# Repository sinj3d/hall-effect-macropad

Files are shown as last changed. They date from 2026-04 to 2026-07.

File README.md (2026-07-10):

# Custom Hall-Effect Macropad





## Overview
A custom-engineered macropad utilizing entirely 3D-printed Hall-effect switches. This project demonstrates end-to-end hardware design, from schematic capture and PCB layout to physical assembly and mechanism tuning. [cite_start]The hardware serves as a development platform for writing custom peripheral firmware in C++ and Rust[cite: 4].

<div align="center">
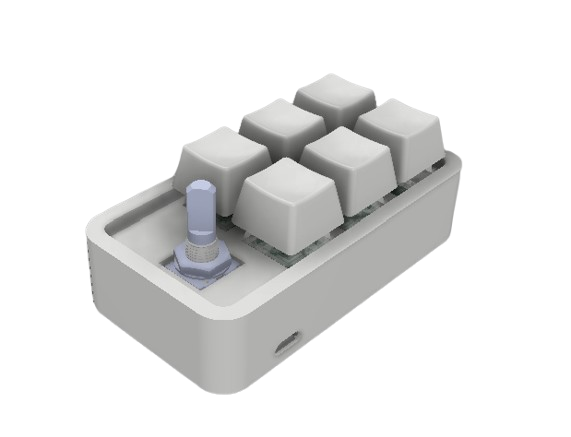
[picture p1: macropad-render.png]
Physical PCB Assembly
  
</div>

## Current Status & Next Steps
**Hardware V1 is fully assembled and mechanically functional.** The custom PCB has been fabricated, populated, and soldered. The 3D-printed magnetic switches are currently undergoing physical fine-tuning to optimize the keystroke smoothness and actuation tolerances. 

**Immediate Next Steps:**
* [cite_start]**Firmware Architecture:** Drafting the low-level firmware in C++/Rust [cite: 4] to handle analog matrix scanning and switch debouncing.
* **Actuation Calibration:** Implementing dynamic actuation point calibration based on the analog Hall-effect sensor outputs.
* **Enclosure Design:** Finalizing the CAD for the external housing.

## Hardware Specifications
* **PCB Design:** Custom 2-layer board designed in KiCad.
* **Switches:** Custom 3D-printed housings utilizing Hall-effect sensors and permanent magnets for frictionless, adjustable actuation.
* **Manufacturing:** Routing, ground pours, and component placement optimized for hand-soldering and mechanical stability.

## Repository Structure

This repository contains the complete hardware definition and firmware files.

* `/Hardware`
    * `/Gerbers` - Ready-to-manufacture fabrication files (Copper, Mask, Silkscreen, Edge Cuts, Drill files).
    * `Macropad Schematic.pdf` - High-resolution electrical schematic for quick review.
    * `/KiCad_Project` - Raw `.kicad_pro`, `.kicad_sch`, and `.kicad_pcb` source files.
* `/CAD`
    * .STL files for the 3D-printed switch mechanisms.
* `/Firmware`
    * `main.cpp` - Firmware source (PlatformIO / Arduino framework)
    * `config.h` - Pin map, keymap, and tuning constants
    * `README.md` - Build, flash, tuning, and troubleshooting guide

## Firmware Quick Start

```bash
pip install platformio
pio run -t upload        # from the repo root, Pro Micro plugged in
pio device monitor       # 115200 baud; type 'h' for tuning commands
```

See [Firmware/README.md](Firmware/README.md) for the pin map, key remapping, sensor tuning, and troubleshooting.

## Visuals & Renders

| PCB Soldered| Schematic Design | Switch Render | 
| :---: | :---: | :---: |
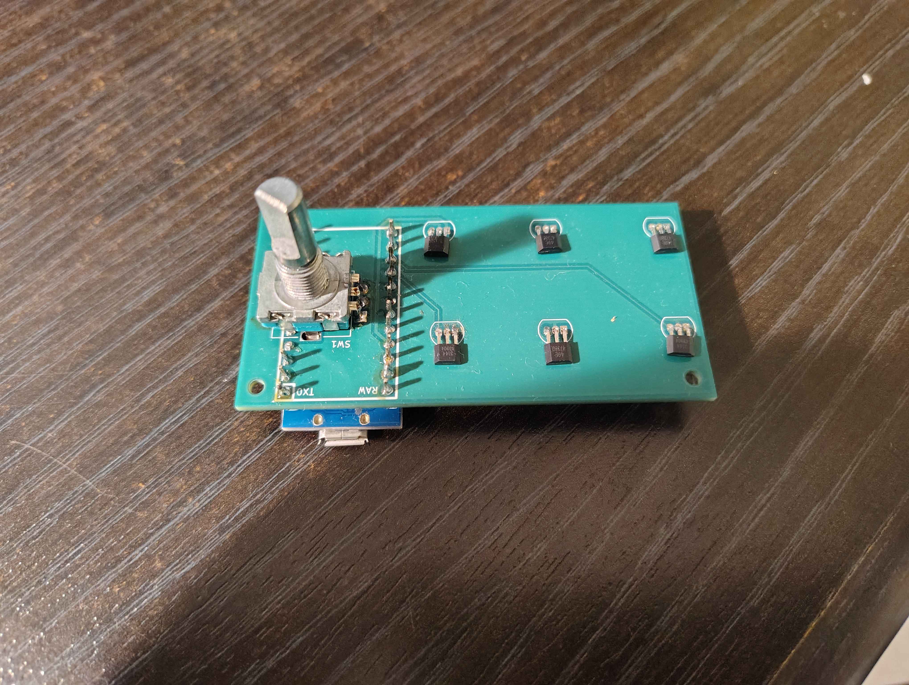
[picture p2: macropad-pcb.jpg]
PCB
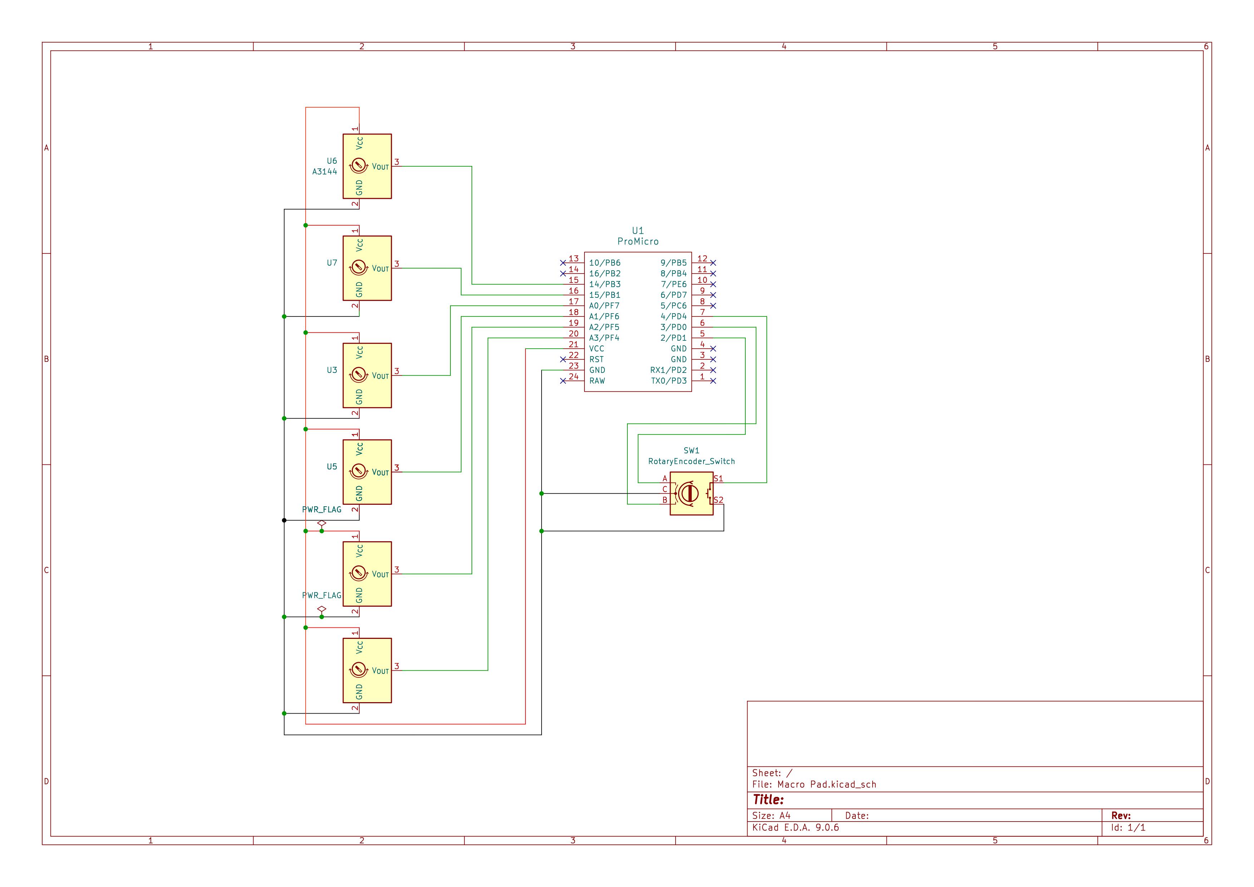
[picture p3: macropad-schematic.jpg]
Schematic
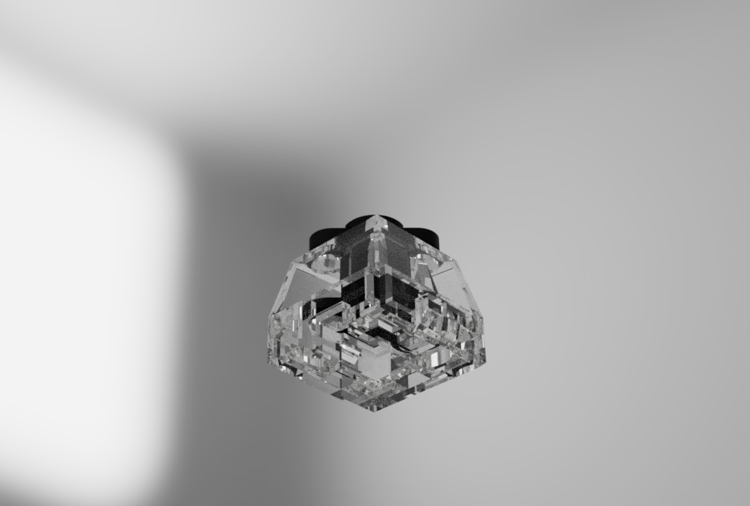
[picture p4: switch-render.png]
Switch
|  |  |

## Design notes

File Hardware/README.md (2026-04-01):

# Custom Hall-Effect Macropad





## Overview
A custom-engineered macropad utilizing entirely 3D-printed Hall-effect switches. This project demonstrates end-to-end hardware design, from schematic capture and PCB layout to physical assembly and mechanism tuning. [cite_start]The hardware serves as a development platform for writing custom peripheral firmware in C++ and Rust[cite: 4].

<div align="center">
  Physical PCB Assembly
</div>

## Current Status & Next Steps
**Hardware V1 is fully assembled and mechanically functional.** The custom PCB has been fabricated, populated, and soldered. The 3D-printed magnetic switches are currently undergoing physical fine-tuning to optimize the keystroke smoothness and actuation tolerances. 

**Immediate Next Steps:**
* [cite_start]**Firmware Architecture:** Drafting the low-level firmware in C++/Rust [cite: 4] to handle analog matrix scanning and switch debouncing.
* **Actuation Calibration:** Implementing dynamic actuation point calibration based on the analog Hall-effect sensor outputs.
* **Enclosure Design:** Finalizing the CAD for the external housing.

## Hardware Specifications
* **PCB Design:** Custom 2-layer board designed in KiCad.
* **Switches:** Custom 3D-printed housings utilizing Hall-effect sensors and permanent magnets for frictionless, adjustable actuation.
* **Manufacturing:** Routing, ground pours, and component placement optimized for hand-soldering and mechanical stability.

## Repository Structure

This repository contains the complete hardware definition files needed to replicate the board.

* `/Hardware`
    * `/Gerbers` - Ready-to-manufacture fabrication files (Copper, Mask, Silkscreen, Edge Cuts, Drill files).
    * `macropad_schematic.pdf` - High-resolution electrical schematic for quick review.
    * `/KiCad_Project` - Raw `.kicad_pro`, `.kicad_sch`, and `.kicad_pcb` source files.
* `/CAD`
    * .STL files for the 3D-printed switch mechanisms.

## Visuals & Renders

| Schematic Design | 3D PCB Render |
| :---: | :---: |
| Schematic | 3D Render |

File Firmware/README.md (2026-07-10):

# Macropad Firmware

Firmware for the 6-key + rotary-encoder Hall-effect macropad, running on a SparkFun Pro Micro (ATmega32U4). Built with PlatformIO on the Arduino framework, using [HID-Project](https://github.com/NicoHood/HID) for NKRO keyboard and media-key (consumer control) output.

## Hardware

| Signal | Pro Micro pin | MCU port | Notes |
|---|---|---|---|
| SS49E sensor 0–3 (WASD) | A3, A2, A1, A0 | PF4–PF7 | Linear analog output, idles near VCC/2 |
| A3144 switch 0 | 15 | PB1 | Open collector, LOW when magnet present |
| A3144 switch 1 | 14 | PB3 | Open collector, LOW when magnet present |
| Encoder A | 2 | PD1 / INT1 | Interrupt-driven quadrature |
| Encoder B | 3 | PD0 / INT0 | Interrupt-driven quadrature |
| Encoder push switch | 4 | PD4 | Active LOW |

The SS49Es must be on A0–A3: PB1/PB3 have no ADC, so those two positions can only host the digital A3144s.

### How analog sensing works

The SS49E idles near VCC/2 and its output swings **up or down** as the magnet approaches, depending on which pole faces the sensor. The firmware captures a per-key baseline at power-up and treats a key as pressed when the reading deviates from that baseline by `ACTUATION_DELTA` counts (released when it falls back below `RELEASE_DELTA`). This works with either magnet orientation and needs no per-key polarity configuration.

Consequence: **don't hold keys down while plugging the board in.** If you did, send `z` over serial to re-capture baselines. Slow drift (temperature, magnet creep) is compensated automatically while keys are idle.

## Build & flash

```bash
pip install platformio        # once
pio run                       # compile (from the repo root)
pio run -t upload             # compile + flash, port auto-detected
pio device monitor            # serial console, 115200 baud
```

If `pio` isn't recognized after installing (pip's Scripts directory not on PATH), use `python -m platformio` in place of `pio` — e.g. `python -m platformio run -t upload`.

If the upload times out, double-tap the reset button on the Pro Micro (this enters the Caterina bootloader for ~8 seconds) and run the upload command again.

## Serial commands (115200 baud)

| Key | Action |
|---|---|
| `v` | Print one status line: filtered value, baseline, and delta/actuation per analog key, digital key states, raw encoder pin levels |
| `p` | Toggle 10 Hz streaming of that status line (use while tuning) |
| `z` | Re-capture analog baselines (release all keys first) |
| `c` | Guided per-key actuation calibration (results saved to EEPROM) |
| `d` | Clear saved calibration, back to the `config.h` defaults |
| `h` | Help |

## Calibrating actuation points (per key)

Each analog key has its own actuation and release point, calibrated in place:

1. Run `pio device monitor` and send `c`.
2. Keep all keys released while it re-zeros, then press and **hold** each WASD key fully, one at a time. Peak travel per key is echoed once a second.
3. After 15 s (or send any character to finish early), each key's actuation point is set to 65% of its measured travel and its release point to 35%, the results are printed, and everything is saved to EEPROM — calibration survives power cycles and re-flashing.

Keys that moved less than `CAL_MIN_TRAVEL` (30 counts) during the window keep their previous thresholds, so you can re-calibrate a single key without touching the others. The 65/35 split is set by `CAL_ACTUATION_PCT` / `CAL_RELEASE_PCT` in `config.h`; the gap between them is the hysteresis that debounces the analog keys — keep it wide to avoid chatter.

Until calibration is run (or after `d` clears it), all keys use the `ACTUATION_DELTA` / `RELEASE_DELTA` defaults from `config.h` (60/35 counts); a close-range neodymium magnet typically swings 150–300 counts at full press.

## Verifying the physical layout

The schematic doesn't say which physical key sits on which pin, so verify once:

- **Key order**: stream with `p`, press each key, and note which channel (`A0`–`A3`, `D0`/`D1`) responds. Reorder `ANALOG_KEY_MAP` / `DIGITAL_KEY_MAP` in `config.h` to match.
- **Encoder pins**: the firmware assumes A=D2, B=D3, switch=D4. Watching the `enc A= B= SW=` fields while rotating slowly and pressing shows which pins actually toggle; adjust `PIN_ENC_*` in `config.h` if they're crossed.
- **Encoder direction**: if volume goes the wrong way, set `ENCODER_REVERSED` to `1`.

## Changing the keymap

Edit `config.h`:

```cpp
static const KeyboardKeycode ANALOG_KEY_MAP[NUM_ANALOG_KEYS] = {KEY_W, KEY_A, KEY_S, KEY_D};
static const KeyboardKeycode DIGITAL_KEY_MAP[NUM_DIGITAL_KEYS] = {KEY_LEFT_SHIFT, KEY_SPACE};

static const ConsumerKeycode ENC_CW_ACTION = MEDIA_VOLUME_UP;
static const ConsumerKeycode ENC_CCW_ACTION = MEDIA_VOLUME_DOWN;
static const ConsumerKeycode ENC_PRESS_ACTION = MEDIA_PLAY_PAUSE;
```

Key names are HID-Project's `KeyboardKeycode` (`KEY_A`–`KEY_Z`, `KEY_F1`–`KEY_F24`, `KEY_LEFT_CTRL`, `KEY_ESC`, ...) and `ConsumerKeycode` (`MEDIA_VOLUME_UP`, `MEDIA_VOL_MUTE`, `MEDIA_NEXT`, `CONSUMER_BROWSER_HOME`, ...). Full lists are in HID-Project's `ImprovedKeylayouts.h` and `ConsumerAPI.h`.

## Troubleshooting

- **An A3144 key never triggers**: the A3144 is unipolar — it only responds to the magnet's **south pole**. Flip the magnet in that switch stem.
- **An analog key is stuck down or dead**: its baseline is probably wrong (key was held at power-up, or the magnet moved). Send `z` with all keys released. If deltas barely move on press, the magnet may be too far from the sensor at the bottom of travel.
- **Encoder skips or double-steps**: try `ENC_STEPS_PER_DETENT = 2` (some encoders are half-step per detent).
- **Upload fails**: double-tap reset, then upload within ~8 seconds. Check `pio device list` shows the board.
- **Two keys are dead**: they're likely the PB1/PB3 positions with SS49Es installed there by mistake — those pins can't do analog. Swap the sensors so the A3144s sit on PB1/PB3.

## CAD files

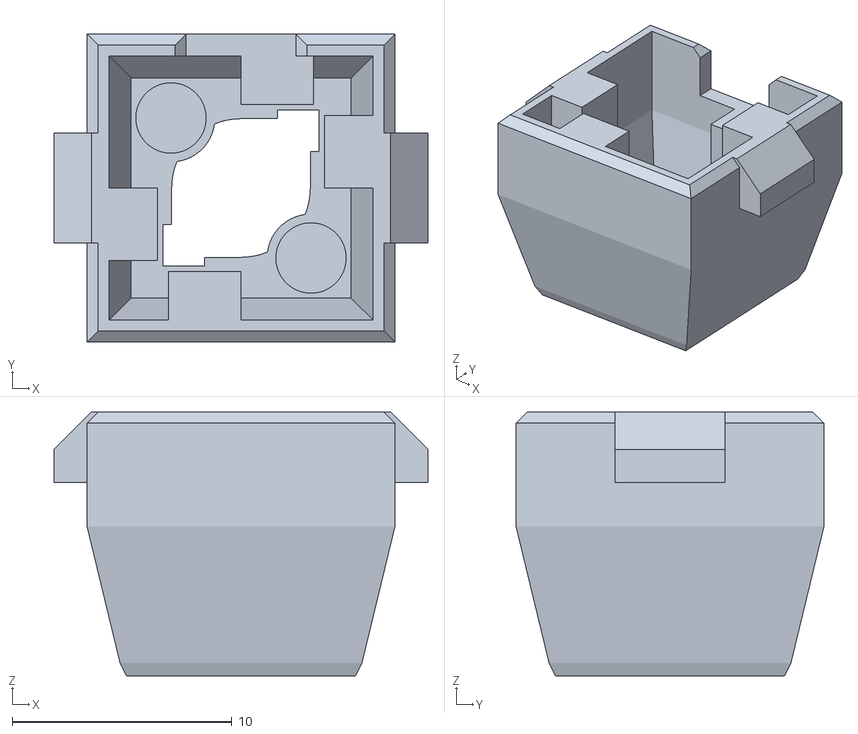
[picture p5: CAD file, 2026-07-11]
CAD/Key Base.stl
17.0 x 14.0 x 12.0

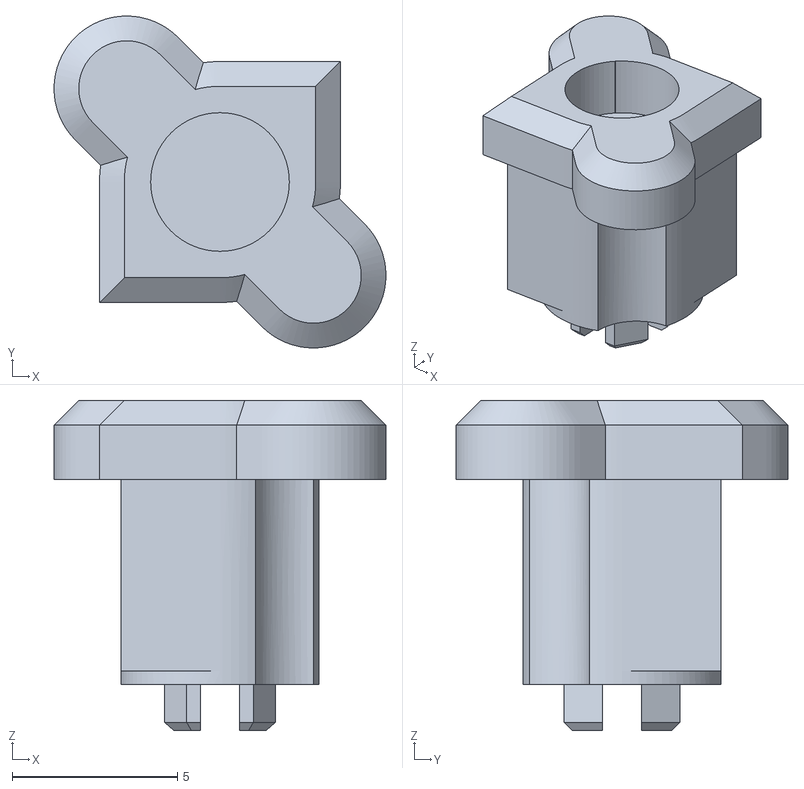
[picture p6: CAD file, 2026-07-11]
CAD/key stem bottom.stl
10.1 x 10.1 x 10.0

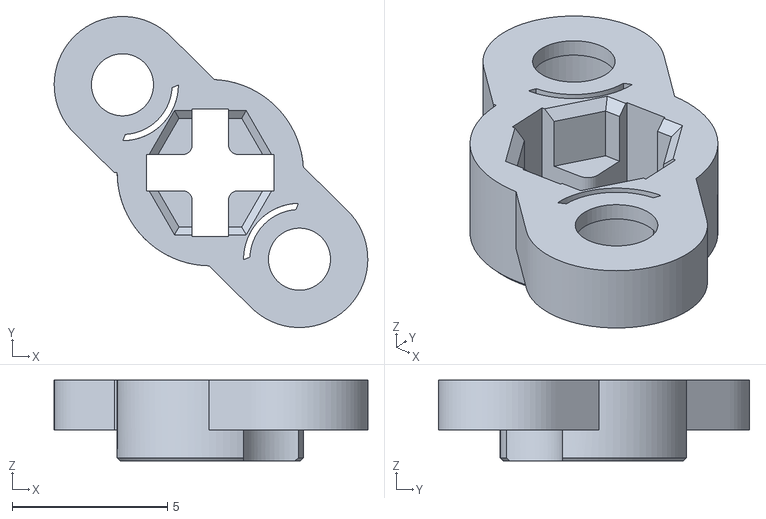
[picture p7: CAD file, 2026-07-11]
CAD/Key stem top.stl
10.1 x 10.0 x 2.60

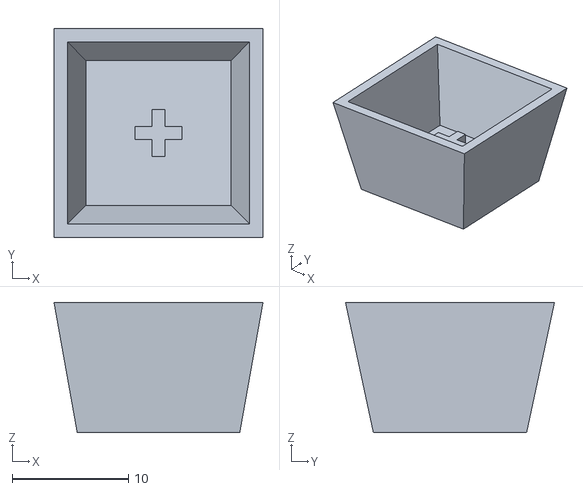
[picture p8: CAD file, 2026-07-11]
CAD/Keycap.stl
18.0 x 18.0 x 11.2

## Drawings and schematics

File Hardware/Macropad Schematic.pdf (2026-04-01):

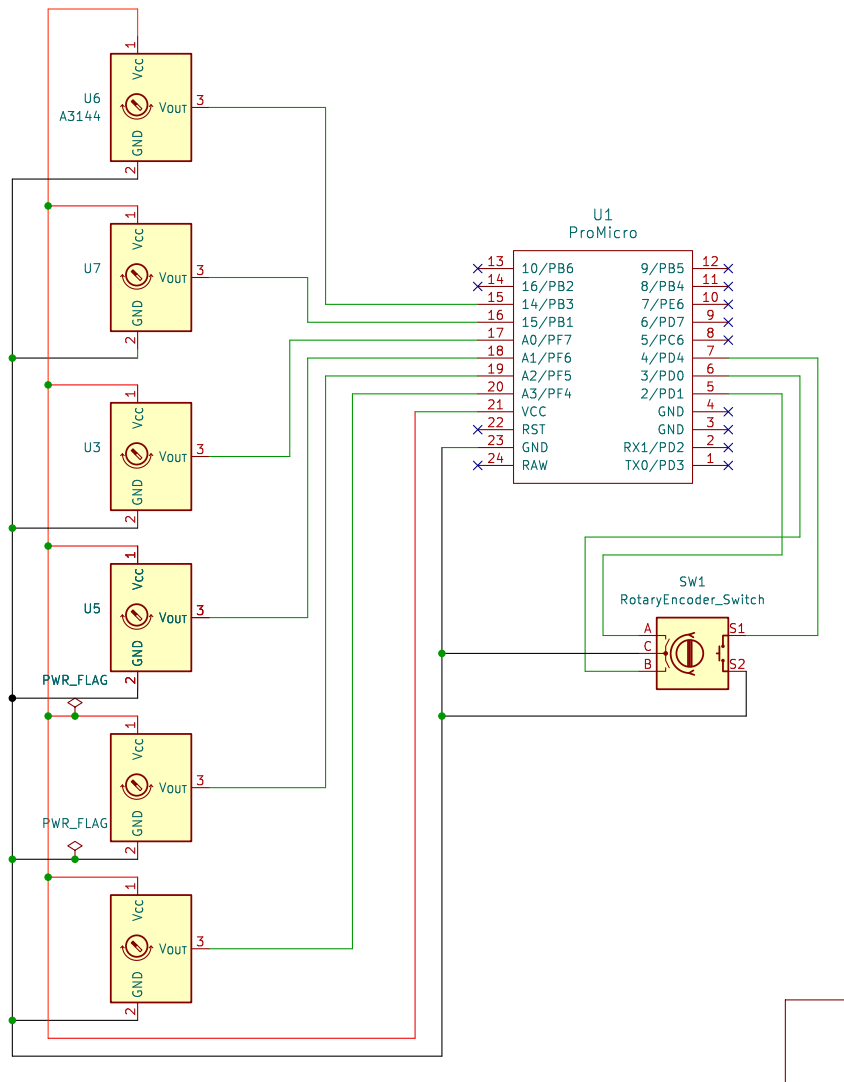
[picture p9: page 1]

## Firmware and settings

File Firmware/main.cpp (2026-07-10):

/*
 * Hall-effect macropad firmware
 * Board: SparkFun Pro Micro (ATmega32U4, 5V/16MHz)
 *
 * Hardware, per Hardware/Macropad Schematic.pdf:
 *   - 4x SS49E linear Hall sensors (analog) on A3/A2/A1/A0 — WASD cluster
 *   - 2x A3144 Hall switches (open collector, active LOW) on D15/D14
 *   - Rotary encoder: A/B on D2/D3 (external interrupts), push switch on D4
 *
 * SS49E keys: the sensor idles near VCC/2 and swings up or down as the magnet
 * approaches, depending on which pole faces it. Each key is compared against a
 * baseline captured at power-up; it counts as pressed once the reading deviates
 * from that baseline by ACTUATION_DELTA and releases below RELEASE_DELTA, so
 * either magnet orientation works. Don't hold keys while plugging the board in
 * (send 'z' over serial to re-zero if you did).
 *
 * Actuation points are per key: serial command 'c' measures each key's full
 * travel and stores actuation/release thresholds in EEPROM ('d' clears them).
 */

#include <Arduino.h>
#include <EEPROM.h>
#include "config.h"

// ---------- SS49E (analog) keys ----------

struct AnalogKey {
  uint16_t filtered;
  uint16_t baseline;
  bool pressed;
};

static AnalogKey analogKeys[NUM_ANALOG_KEYS];

static uint16_t readAveraged(uint8_t pin, uint8_t samples) {
  uint16_t sum = 0;
  for (uint8_t i = 0; i < samples; i++) sum += analogRead(pin);
  return sum / samples;
}

static void captureBaselines() {
  for (uint8_t i = 0; i < NUM_ANALOG_KEYS; i++) {
    analogKeys[i].baseline = readAveraged(ANALOG_KEY_PINS[i], 32);
    analogKeys[i].filtered = analogKeys[i].baseline;
  }
}

static uint16_t deltaFromBaseline(const AnalogKey &k) {
  return k.filtered > k.baseline ? k.filtered - k.baseline : k.baseline - k.filtered;
}

// ---------- Per-key actuation thresholds (EEPROM-backed) ----------

struct Calibration {
  uint8_t magic;
  uint16_t actuation[NUM_ANALOG_KEYS];
  uint16_t release[NUM_ANALOG_KEYS];
};

static const uint8_t CAL_MAGIC = 0xC4;
static Calibration cal;

static void loadDefaultCal() {
  for (uint8_t i = 0; i < NUM_ANALOG_KEYS; i++) {
    cal.actuation[i] = ACTUATION_DELTA;
    cal.release[i] = RELEASE_DELTA;
  }
}

static void loadCalibration() {
  Calibration stored;
  EEPROM.get(0, stored);
  if (stored.magic == CAL_MAGIC) cal = stored;
  else loadDefaultCal();
}

static void saveCalibration() {
  cal.magic = CAL_MAGIC;
  EEPROM.put(0, cal);  // update semantics: only changed bytes get written
}

static void scanAnalogKeys() {
  for (uint8_t i = 0; i < NUM_ANALOG_KEYS; i++) {
    AnalogKey &k = analogKeys[i];
    uint16_t raw = readAveraged(ANALOG_KEY_PINS[i], ADC_SAMPLES);
    k.filtered = (k.filtered * 3 + raw + 2) / 4;

    uint16_t delta = deltaFromBaseline(k);
    if (!k.pressed && delta >= cal.actuation[i]) {
      k.pressed = true;
      NKROKeyboard.press(ANALOG_KEY_MAP[i]);
    } else if (k.pressed && delta <= cal.release[i]) {
      k.pressed = false;
      NKROKeyboard.release(ANALOG_KEY_MAP[i]);
    }
  }
}

// Nudge idle baselines one count toward the current reading so slow drift
// (temperature, magnet creep) doesn't eat into the actuation margin.
static void trackBaselineDrift() {
  static uint32_t lastMs = 0;
  uint32_t now = millis();
  if (now - lastMs < BASELINE_TRACK_MS) return;
  lastMs = now;
  for (uint8_t i = 0; i < NUM_ANALOG_KEYS; i++) {
    AnalogKey &k = analogKeys[i];
    if (k.pressed || deltaFromBaseline(k) > cal.release[i]) continue;
    if (k.filtered > k.baseline) k.baseline++;
    else if (k.filtered < k.baseline) k.baseline--;
  }
}

// ---------- A3144 (digital) keys + encoder button ----------

struct DebouncedInput {
  bool state;
  bool lastReading;
  uint32_t lastEdgeMs;
};

static DebouncedInput digitalKeys[NUM_DIGITAL_KEYS];
static DebouncedInput encButton;

// Returns true when the debounced state just changed.
static bool debounce(DebouncedInput &d, bool reading, uint32_t now) {
  if (reading != d.lastReading) {
    d.lastReading = reading;
    d.lastEdgeMs = now;
  }
  if (reading != d.state && now - d.lastEdgeMs >= DEBOUNCE_MS) {
    d.state = reading;
    return true;
  }
  return false;
}

static void scanDigitalKeys() {
  uint32_t now = millis();
  for (uint8_t i = 0; i < NUM_DIGITAL_KEYS; i++) {
    bool active = digitalRead(DIGITAL_KEY_PINS[i]) == LOW;  // sinks LOW near magnet
    if (debounce(digitalKeys[i], active, now)) {
      if (digitalKeys[i].state) NKROKeyboard.press(DIGITAL_KEY_MAP[i]);
      else NKROKeyboard.release(DIGITAL_KEY_MAP[i]);
    }
  }

  bool swActive = digitalRead(PIN_ENC_SW) == LOW;
  if (debounce(encButton, swActive, now) && encButton.state) {
    Consumer.write(ENC_PRESS_ACTION);
  }
}

// ---------- Rotary encoder (quadrature, interrupt-driven) ----------

static volatile int8_t encDetents = 0;
static uint8_t encPrevBits = 0;

static void encoderIsr() {
  static const int8_t QDEC[16] = {0, -1, 1, 0, 1, 0, 0, -1, -1, 0, 0, 1, 0, 1, -1, 0};
  static int8_t accum = 0;
  uint8_t bits = (uint8_t)((digitalRead(PIN_ENC_A) << 1) | digitalRead(PIN_ENC_B));
  accum += QDEC[((encPrevBits << 2) | bits) & 0x0F];
  encPrevBits = bits;
  if (accum >= (int8_t)ENC_STEPS_PER_DETENT) {
    encDetents++;
    accum = 0;
  } else if (accum <= -(int8_t)ENC_STEPS_PER_DETENT) {
    encDetents--;
    accum = 0;
  }
}

static void pumpEncoder() {
  noInterrupts();
  int8_t d = encDetents;
  encDetents = 0;
  interrupts();
  if (d == 0) return;
#if ENCODER_REVERSED
  d = -d;
#endif
  while (d > 0) { Consumer.write(ENC_CW_ACTION); d--; }
  while (d < 0) { Consumer.write(ENC_CCW_ACTION); d++; }
}

// ---------- Serial tuning interface ----------

static bool streaming = false;

static void printStatus() {
  for (uint8_t i = 0; i < NUM_ANALOG_KEYS; i++) {
    const AnalogKey &k = analogKeys[i];
    Serial.print(F("A"));
    Serial.print(i);
    Serial.print(F(":val="));
    Serial.print(k.filtered);
    Serial.print(F(" base="));
    Serial.print(k.baseline);
    Serial.print(F(" d="));
    Serial.print(deltaFromBaseline(k));
    Serial.print(F("/"));
    Serial.print(cal.actuation[i]);
    Serial.print(k.pressed ? F("*  ") : F("   "));
  }
  Serial.print(F("| D0="));
  Serial.print(digitalKeys[0].state ? F("DOWN") : F("up"));
  Serial.print(F(" D1="));
  Serial.print(digitalKeys[1].state ? F("DOWN") : F("up"));
  Serial.print(F(" | enc A="));
  Serial.print(digitalRead(PIN_ENC_A));
  Serial.print(F(" B="));
  Serial.print(digitalRead(PIN_ENC_B));
  Serial.print(F(" SW="));
  Serial.println(digitalRead(PIN_ENC_SW));
}

// Guided per-key calibration: re-zero, record each key's peak travel while the
// user holds it down, then derive per-key actuation/release points from it.
// Blocks the scan loop on purpose; no key events are sent while it runs.
static void runCalibration() {
  for (uint8_t i = 0; i < NUM_ANALOG_KEYS; i++) analogKeys[i].pressed = false;
  NKROKeyboard.releaseAll();

  Serial.println(F("Calibration: release all keys, re-zeroing..."));
  delay(500);
  captureBaselines();

  Serial.println(F("Now press and HOLD each analog key fully, one at a time."));
  Serial.print(F("Capturing for "));
  Serial.print(CAL_WINDOW_MS / 1000);
  Serial.println(F(" s -- send any key to finish early."));

  uint16_t peak[NUM_ANALOG_KEYS] = {0};
  uint32_t start = millis();
  uint32_t lastEcho = start;
  while (millis() - start < CAL_WINDOW_MS && !Serial.available()) {
    for (uint8_t i = 0; i < NUM_ANALOG_KEYS; i++) {
      uint16_t raw = readAveraged(ANALOG_KEY_PINS[i], ADC_SAMPLES);
      uint16_t b = analogKeys[i].baseline;
      uint16_t delta = raw > b ? raw - b : b - raw;
      if (delta > peak[i]) peak[i] = delta;
    }
    if (millis() - lastEcho >= 1000) {
      lastEcho = millis();
      Serial.print(F("  peak travel:"));
      for (uint8_t i = 0; i < NUM_ANALOG_KEYS; i++) {
        Serial.print(' ');
        Serial.print(peak[i]);
      }
      Serial.println();
    }
  }
  while (Serial.available()) Serial.read();

  for (uint8_t i = 0; i < NUM_ANALOG_KEYS; i++) {
    Serial.print(F("A"));
    Serial.print(i);
    if (peak[i] < CAL_MIN_TRAVEL) {
      Serial.print(F(": travel "));
      Serial.print(peak[i]);
      Serial.println(F(" too small -- keeping previous thresholds"));
      continue;
    }
    cal.actuation[i] = (uint16_t)(((uint32_t)peak[i] * CAL_ACTUATION_PCT) / 100);
    cal.release[i] = (uint16_t)(((uint32_t)peak[i] * CAL_RELEASE_PCT) / 100);
    Serial.print(F(": travel="));
    Serial.print(peak[i]);
    Serial.print(F(" act="));
    Serial.print(cal.actuation[i]);
    Serial.print(F(" rel="));
    Serial.println(cal.release[i]);
  }
  saveCalibration();
  Serial.println(F("Saved to EEPROM."));

  noInterrupts();
  encDetents = 0;  // discard rotation accumulated while blocked here
  interrupts();
}

static void printHelp() {
  Serial.println(F("Hall-effect macropad -- serial commands:"));
  Serial.println(F("  v  print one status line (values, baselines, delta/actuation, pin states)"));
  Serial.println(F("  p  toggle 10 Hz status streaming (for threshold tuning)"));
  Serial.println(F("  z  re-capture analog baselines (release all keys first)"));
  Serial.println(F("  c  calibrate per-key actuation points (guided, saved to EEPROM)"));
  Serial.println(F("  d  clear saved calibration, back to config.h defaults"));
  Serial.println(F("  h  this help"));
}

static void handleSerial() {
  while (Serial.available()) {
    switch (Serial.read()) {
      case 'v':
        printStatus();
        break;
      case 'p':
        streaming = !streaming;
        break;
      case 'z':
        captureBaselines();
        Serial.println(F("Baselines re-zeroed."));
        break;
      case 'c':
        runCalibration();
        break;
      case 'd':
        EEPROM.write(0, 0xFF);  // invalidate the stored block
        loadDefaultCal();
        Serial.println(F("Calibration cleared; using config.h defaults."));
        break;
      case 'h':
      case '?':
        printHelp();
        break;
      default:
        break;
    }
  }
  if (streaming) {
    static uint32_t lastMs = 0;
    if (millis() - lastMs >= 100) {
      lastMs = millis();
      printStatus();
    }
  }
}

// ---------- Arduino entry points ----------

void setup() {
  Serial.begin(SERIAL_BAUD);

  for (uint8_t i = 0; i < NUM_ANALOG_KEYS; i++) pinMode(ANALOG_KEY_PINS[i], INPUT);
  for (uint8_t i = 0; i < NUM_DIGITAL_KEYS; i++) pinMode(DIGITAL_KEY_PINS[i], INPUT_PULLUP);
  pinMode(PIN_ENC_A, INPUT_PULLUP);
  pinMode(PIN_ENC_B, INPUT_PULLUP);
  pinMode(PIN_ENC_SW, INPUT_PULLUP);

  delay(50);  // let the sensors power up before zeroing
  captureBaselines();
  loadCalibration();

  encPrevBits = (uint8_t)((digitalRead(PIN_ENC_A) << 1) | digitalRead(PIN_ENC_B));
  attachInterrupt(digitalPinToInterrupt(PIN_ENC_A), encoderIsr, CHANGE);
  attachInterrupt(digitalPinToInterrupt(PIN_ENC_B), encoderIsr, CHANGE);

  NKROKeyboard.begin();
  Consumer.begin();
}

void loop() {
  scanAnalogKeys();
  scanDigitalKeys();
  trackBaselineDrift();
  pumpEncoder();
  handleSerial();
}

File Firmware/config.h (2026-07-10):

#pragma once
/*
 * Macropad configuration — pin map, keymap, tuning.
 *
 * Pin assignments follow Hardware/Macropad Schematic.pdf. Normally only the
 * keymaps and the tuning section should need editing. Key names come from
 * HID-Project: KeyboardKeycode (KEY_W, KEY_F13, KEY_LEFT_SHIFT, ...) and
 * ConsumerKeycode (MEDIA_VOLUME_UP, MEDIA_PLAY_PAUSE, MEDIA_VOL_MUTE, ...).
 */

#include <HID-Project.h>

// ---- 4x SS49E linear Hall sensors (analog) — the WASD cluster ----
// PB1/PB3 have no ADC on the ATmega32U4, so the SS49Es must be the four
// sensors wired to A3..A0. Reorder ANALOG_KEY_MAP after checking which
// physical key moves which channel (serial command 'p').
#define NUM_ANALOG_KEYS 4
static const uint8_t ANALOG_KEY_PINS[NUM_ANALOG_KEYS] = {A3, A2, A1, A0};  // PF4 PF5 PF6 PF7
static const KeyboardKeycode ANALOG_KEY_MAP[NUM_ANALOG_KEYS] = {KEY_W, KEY_A, KEY_S, KEY_D};

// ---- 2x A3144 Hall switches (digital, open collector, active LOW) ----
#define NUM_DIGITAL_KEYS 2
static const uint8_t DIGITAL_KEY_PINS[NUM_DIGITAL_KEYS] = {15, 14};  // PB1, PB3
static const KeyboardKeycode DIGITAL_KEY_MAP[NUM_DIGITAL_KEYS] = {KEY_LEFT_SHIFT, KEY_SPACE};

// ---- Rotary encoder ----
static const uint8_t PIN_ENC_A = 2;   // PD1 / INT1
static const uint8_t PIN_ENC_B = 3;   // PD0 / INT0
static const uint8_t PIN_ENC_SW = 4;  // PD4
#define ENCODER_REVERSED 0            // set to 1 if rotation goes the wrong way
static const uint8_t ENC_STEPS_PER_DETENT = 4;  // 4 for most EC11s; 2 for half-step types

static const ConsumerKeycode ENC_CW_ACTION = MEDIA_VOLUME_UP;
static const ConsumerKeycode ENC_CCW_ACTION = MEDIA_VOLUME_DOWN;
static const ConsumerKeycode ENC_PRESS_ACTION = MEDIA_PLAY_PAUSE;

// ---- Tuning ----
// SS49E deltas are in ADC counts (0-1023 over 0-5 V, roughly 0.3 counts/gauss).
// These are the defaults used until per-key calibration is run (serial 'c');
// calibrated per-key thresholds live in EEPROM and override them.
static const uint16_t ACTUATION_DELTA = 60;
static const uint16_t RELEASE_DELTA = 35;

// ---- Per-key calibration (serial command 'c') ----
// Calibration measures each key's full-press delta and derives its actuation
// and release points from it. The gap between the two is hysteresis.
static const uint8_t CAL_ACTUATION_PCT = 65;  // actuation point, % of full travel
static const uint8_t CAL_RELEASE_PCT = 35;    // release point, % of full travel
static const uint16_t CAL_MIN_TRAVEL = 30;    // counts; keys moving less keep old values
static const uint16_t CAL_WINDOW_MS = 15000;  // capture window length

static const uint8_t ADC_SAMPLES = 4;            // averaged per reading
static const uint8_t DEBOUNCE_MS = 8;            // A3144 keys + encoder button
static const uint16_t BASELINE_TRACK_MS = 1000;  // idle drift compensation interval
static const uint32_t SERIAL_BAUD = 115200;

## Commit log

2026-04-01 moving and scaffolding project
    [Key bottom.stl, Key stem top.stl, Key top.stl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]
2026-07-10 Add Pro Micro firmware for Hall-effect keys and encoder
    - 4x SS49E analog keys (WASD): baseline-relative sensing with hysteresis
    debouncing, per-key actuation points calibrated over serial and
    persisted in EEPROM
    - 2x A3144 digital keys (active LOW) with time-based debounce
    - Interrupt-driven quadrature decoding for the rotary encoder, media-key
    output via HID-Project
    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
2026-07-11 changed CAD to an open end base inspired by riskey for better rail coverage
    [Key Base.stl, Key bottom.stl, Key stem top.stl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]
